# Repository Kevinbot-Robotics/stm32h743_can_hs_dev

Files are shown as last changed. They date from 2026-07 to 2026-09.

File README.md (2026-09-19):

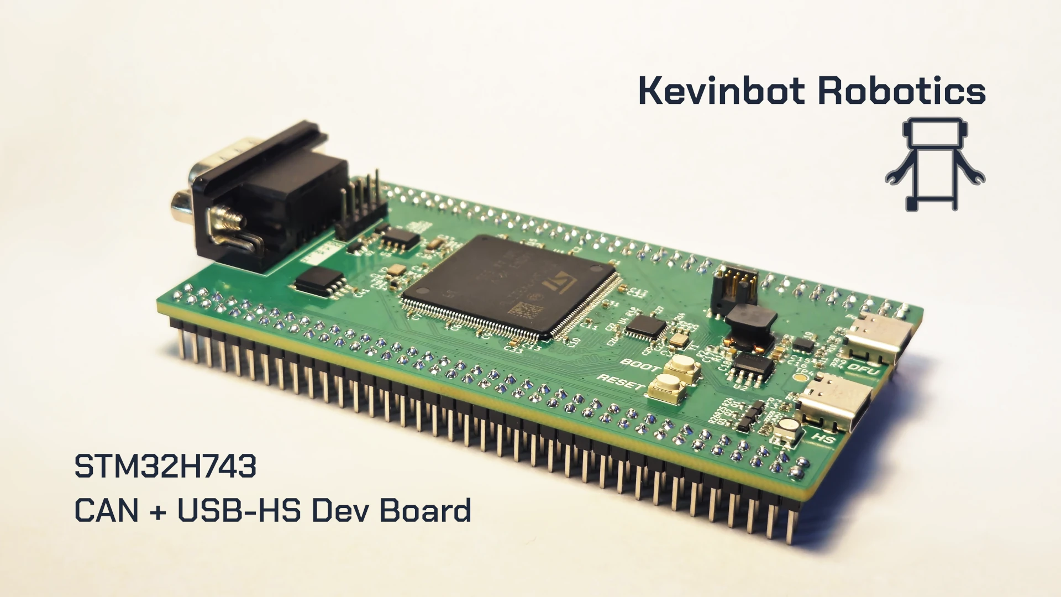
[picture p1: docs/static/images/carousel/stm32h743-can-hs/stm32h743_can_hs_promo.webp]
Board Image


# STM32H743 CAN + USB-HS Dev Board

An STM32H743 development board with on-board USB-HS and CAN-FD (up to 8Mbit/s)

## Documentation

Docs are available on [kevinbot.net](https://kevinbot.net/dev/stm32h743-can-hs/).
Documentation is licensed under the [CC BY-SA 4.0](https://creativecommons.org/licenses/by-sa/4.0/) license.

## Features

* STM32H743
* CAN-FD using DE-9 Industrial connector
* High Speed USB 2.0 using USB3300 ULPI PHY
* 128Mbit QuadSPI NOR flash
* SWD and JTAG debug using STDC14 Debug connector
* USB-C ports for DFU and HS
* Power path switching from HS and DFU port
* RGB LED
* Boot/Reset buttons

---

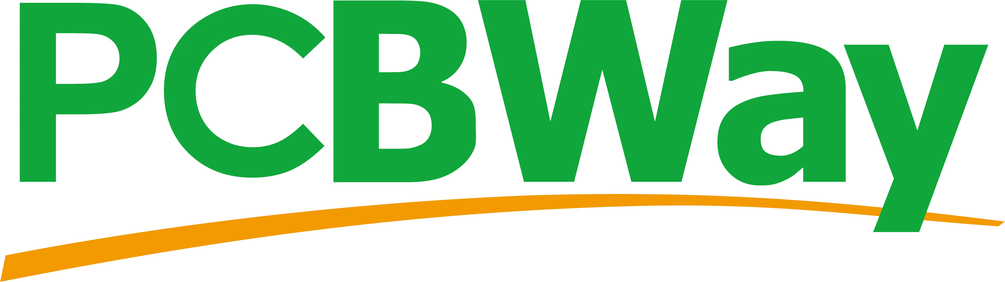
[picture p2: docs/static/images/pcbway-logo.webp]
PCBWay logo


Prototypes for this project were sponsored by [PCBWay](https://www.pcbway.com/).

With their high-quality advanced PCB fabrication, fast turnaround, and excellent customer service, I recommend them for all of your PCB needs.

[Order online here, for as low at $5](https://www.pcbway.com/orderonline.aspx)

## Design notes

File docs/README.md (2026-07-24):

# STM32H743 CAN + USB-HS — Documentation

Source for the STM32H743 CAN + USB-HS dev board documentation.

This is a self-contained [Hugo](https://gohugo.io/) module. It is consumed by
[kevinbot.net](https://kevinbot.net) as a Hugo module, but it can also be built
and previewed on its own so the docs can be published and contributed to
independently of the main site.

## Preview locally

Requires the extended edition of Hugo.

```sh
hugo server
```

The docs are served under `/dev/stm32h743-can-hs/` (the same path they occupy on
kevinbot.net), so every internal link and asset path resolves identically in
both builds.

## Layout

- `content/` — the documentation pages (Markdown).
- `static/` — interactive BOM, Pinion pinout viewer, and carousel images.
- `data/galleries/` — image list for the front-page carousel.
- `layouts/shortcodes/` — the `carousel` and `pinion` shortcodes (mirrored from
  kevinbot.net so this site renders standalone; the main site's copies take
  precedence when integrated).

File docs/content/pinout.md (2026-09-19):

---
title: "Pinout"
editURL: https://github.com/Kevinbot-Robotics/stm32h743_can_hs_dev/edit/master/docs/content/pinout.md
weight: 1
prev: /dev/stm32h743-can-hs
---

An interactive pinout diagram is available below. JavaScript is required to view it. Use the link below if it doesn't load automatically.

{{< pinion spec="/pinion-rev1.1/stm32h743-can-hs" >}}
<a href="/pinion-rev1.1/stm32h743-can-hs/pinion.html" target="_blank">Open Interactive Diagram in New Tab</a>

{{< callout type="note" >}}
  Looking for the Rev 1.0 pinout? [Click here](/pinion-rev1.0/stm32h743-can-hs/pinion.html)
{{< /callout >}}

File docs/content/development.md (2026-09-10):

---
title: "Development"
editURL: https://github.com/Kevinbot-Robotics/stm32h743_can_hs_dev/edit/master/docs/content/development.md
weight: 4
---

This project requires [KiCad](https://www.kicad.org/) 10.0.5 or compatible.

### Building documentation

This project uses a Makefile for building. Documentation requires [Hugo](https://gohugo.io/), and a system Python interpreter with the KiCAD API.

Only Linux is supported for now. WSL within Windows may work.

Run `make all` to create a Python environment, rebuild docs, pinout diagrams, and the interactive BOM.

{{< callout type="warning" >}}
  This step may take a few minutes, use `make docs` if you only want to update the docs without rebuilding the interactive assets.
{{< /callout >}}

Run `make docs` to rebuild the markdown documentation, re-using the pre-built interactive assets (they are included in this repo)

Run `make ibom` to rebuild the interactive BOM. The new BOM will be located in the `bom/` directory, and `docs/static/ibom/`

Run `make pinout` to rebuild the interactive pinout. The built pinout will be located in `docs/static/pinion/`

{{< callout type="warning" >}}
  This step may take a few minutes.
{{< /callout >}}

Run `make clean` to remove the Python environment and built docs.

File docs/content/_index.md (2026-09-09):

---
title: STM32H743 CAN + USB-HS Dev Board
editURL: https://github.com/Kevinbot-Robotics/stm32h743_can_hs_dev/edit/master/docs/content/_index.md
cascade:
  type: docs
aliases:
  - /743-can-hs
  - /h743-can-hs
next: pinout
---

An STM32H743 development board with on-board USB-HS and CAN-FD (up to 8Mbit/s)

{{< carousel gallery="stm32h743-can-hs" >}}

{{< hextra/hero-button text="View Project on GitHub" link="https://github.com/Kevinbot-Robotics/stm32h743_can_hs_dev" >}}

---

<div style="display: flex; flex-direction: row; align-items: center; gap: 1em;">
    <a href="https://certification.oshwa.org/us002841.html">
    OSHW US2841
    OSHW US2841
    </a>
    <p>This project is <a href="https://certification.oshwa.org/us002841.html">certified</a> by the Open Source Hardware Association</p>
</div>

<style>

.light-only {
  display: block;
}

.dark-only {
  display: none;
}

.dark .light-only,
html.dark .light-only {
  display: none;
}

.dark .dark-only,
html.dark .dark-only {
  display: block;
}
</style>

---

## Features

* STM32H743 microcontroller with 116 I/O pins exposed
* CAN-FD using DE-9 connector using industrial standard pinout
* High Speed USB 2.0 using USB3300 ULPI PHY
* 128Mbit QuadSPI NOR flash
* SWD debug using MIPI-10 Cortex Debug connector
* USB-C ports for DFU and HS
* Power path switching from HS and DFU port and backfeed prevention
* RGB LED
* Boot/Reset buttons

## Programming

The board can be programmed via the DFU port using the DFU bootloader by pressing BOOT and RESET to put the board into DFU mode.

The board may also be programmed/debugged using the MIPI-10 Cortex Debug connector.

## Development

The board supports any toolchain that supports the STM32H743 microcontroller, including the STM32CubeIDE and Zephyr.
Zephyr device trees and board configurations will be available in the future.

## Design Resources

{{< cards cols="3" >}}
  {{< card
    title="Simplified CAD Model"
    subtitle="Simplified 3D CAD model with passive components removed, STEP format"
    image="/images/resources/simplified-cad.png"
    link="https://raw.githubusercontent.com/Kevinbot-Robotics/stm32h743_can_hs_dev/refs/heads/master/stm32h743_can_hs_simplified.step"
  >}}
  {{< card
    title="Full CAD Model"
    subtitle="Complete 3D CAD model including passive components, STEP format"
    image="/images/resources/complete-cad.png"
    link="https://raw.githubusercontent.com/Kevinbot-Robotics/stm32h743_can_hs_dev/refs/heads/master/stm32h743_can_hs_full.step"
  >}}
  {{< card
    title="KiCAD Symbol & Footprint"
    subtitle="Coming Soon!<br>KiCAD 10 Symbol, Footprint, and 3D Model"
    image="/images/resources/coming-soon.png"
  >}}
{{< /cards >}}

---

PCBWay logo

Prototypes for this project were sponsored by [PCBWay](https://www.pcbway.com/).

With their high-quality advanced PCB fabrication, fast turnaround, and excellent customer service, I recommend them for all of your PCB needs.

[Order online here, for as low at $5](https://www.pcbway.com/orderonline.aspx)

## License

Hardware is licensed under the [GPL-3.0](https://www.gnu.org/licenses/gpl-3.0.html) license.
<br>
Documentation is licensed under the [CC BY-SA 4.0](https://creativecommons.org/licenses/by-sa/4.0/) license.

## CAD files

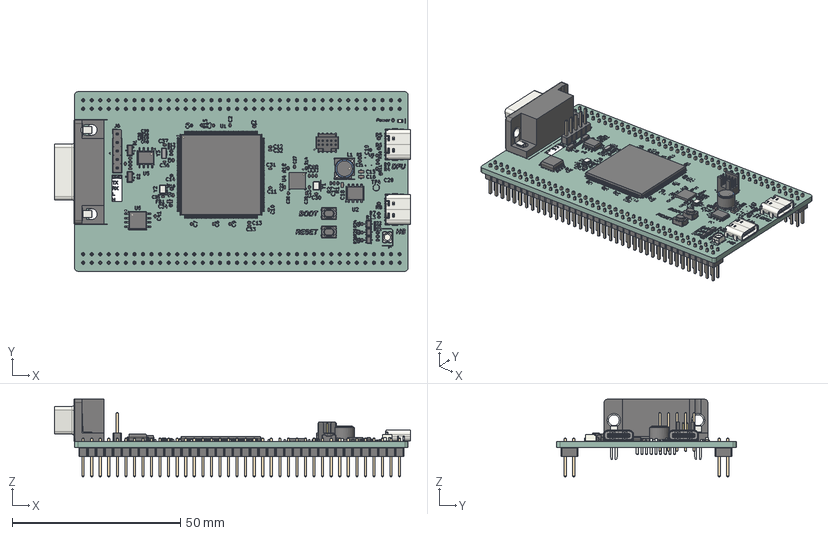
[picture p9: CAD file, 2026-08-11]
stm32h743_can_hs_full.step
105.7 x 53.3 x 23.0 mm
R_0402_1005Metric x 27
C_0402_1005Metric x 38
C_0603_1608Metric x 3
DSUB-9_Pins_Horizontal_P2.77x2.84mm_EdgePinOffset4.94mm_Housed_ MountingHolesOffset4.94mm
SW_SPST_PTS810 x 2
L_0603_1608Metric
USB_C_Receptacle_16P_TopMnt_Horizontal_GCT_USB4105-xx-A x 2
LED_RGB_Wuerth-PLCC4_3.2x2.8mm_150141M173100
LQFP-176_24x24mm_P0.5mm
Oscillator_SMD_SeikoEpson_SG210-4Pin_2.5x2.0mm x 2
TI_SO-PowerPAD-8
SOIC-8_5.3x5.3mm_P1.27mm
SOT-23 x 2
SOT-323_SC-70 x 3
SOIC-8_3.9x4.9mm_P1.27mm
L_TDK_SLF6045
PinHeader_1x05_P254mm_Vertical
FTSH-105-01-L-DV-K_body
FTSH-105-01-L-DV-K_pins1
FTSH-105-01-L-DV-K_pins2
LED_0603_1608Metric
Crystal_SMD_3215-2Pin_3.2x1.5mm
QFN-32-1EP_5x5mm_Pitch0.5mm
PinHeader_2x38_P254mm_Vertical x 2
stm32h743_can_hs_silkscreen x 2
stm32h743_can_hs_PCB

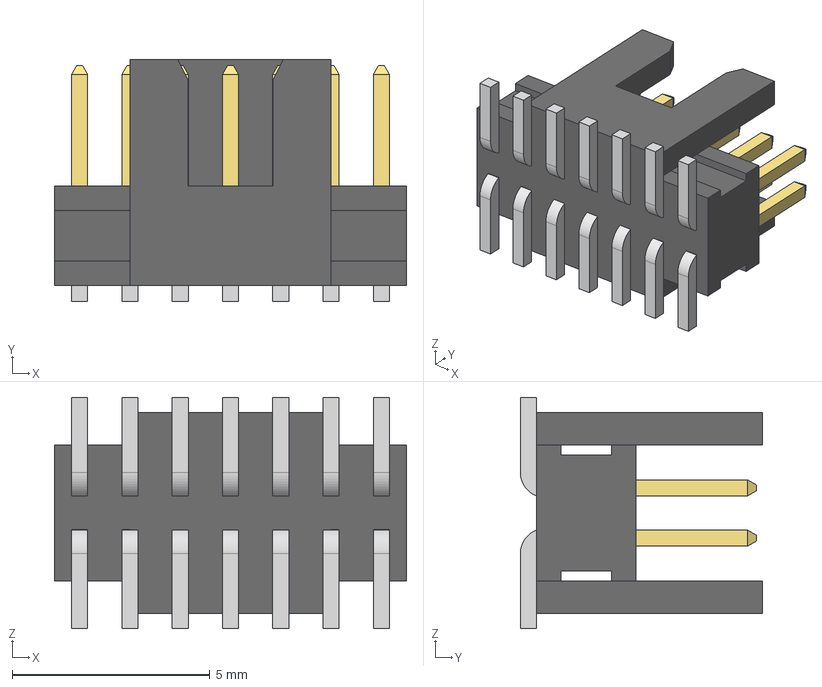
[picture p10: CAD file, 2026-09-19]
SAMTEC_FTSH-107-01-X-DV-K.3dmodels/FTSH-107-01-L-DV-K.stp
8.89 x 6.12 x 5.84 mm
FTSH-107-01-L-DV-K_body
FTSH-107-01-L-DV-K_pins1
FTSH-107-01-L-DV-K_pins2

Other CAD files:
stm32h743_can_hs_simplified.step

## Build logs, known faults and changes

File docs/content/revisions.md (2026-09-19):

---
title: "Revision History"
editURL: https://github.com/Kevinbot-Robotics/stm32h743_can_hs_dev/edit/master/docs/content/revisions.md
weight: 3
---

## 1.1

* Replace debug header with STDC14 to include JTAG support and UART
* Added PA13 to exposed I/O pins
* Added silkscreen label for debug header

## 1.0

* Initial release

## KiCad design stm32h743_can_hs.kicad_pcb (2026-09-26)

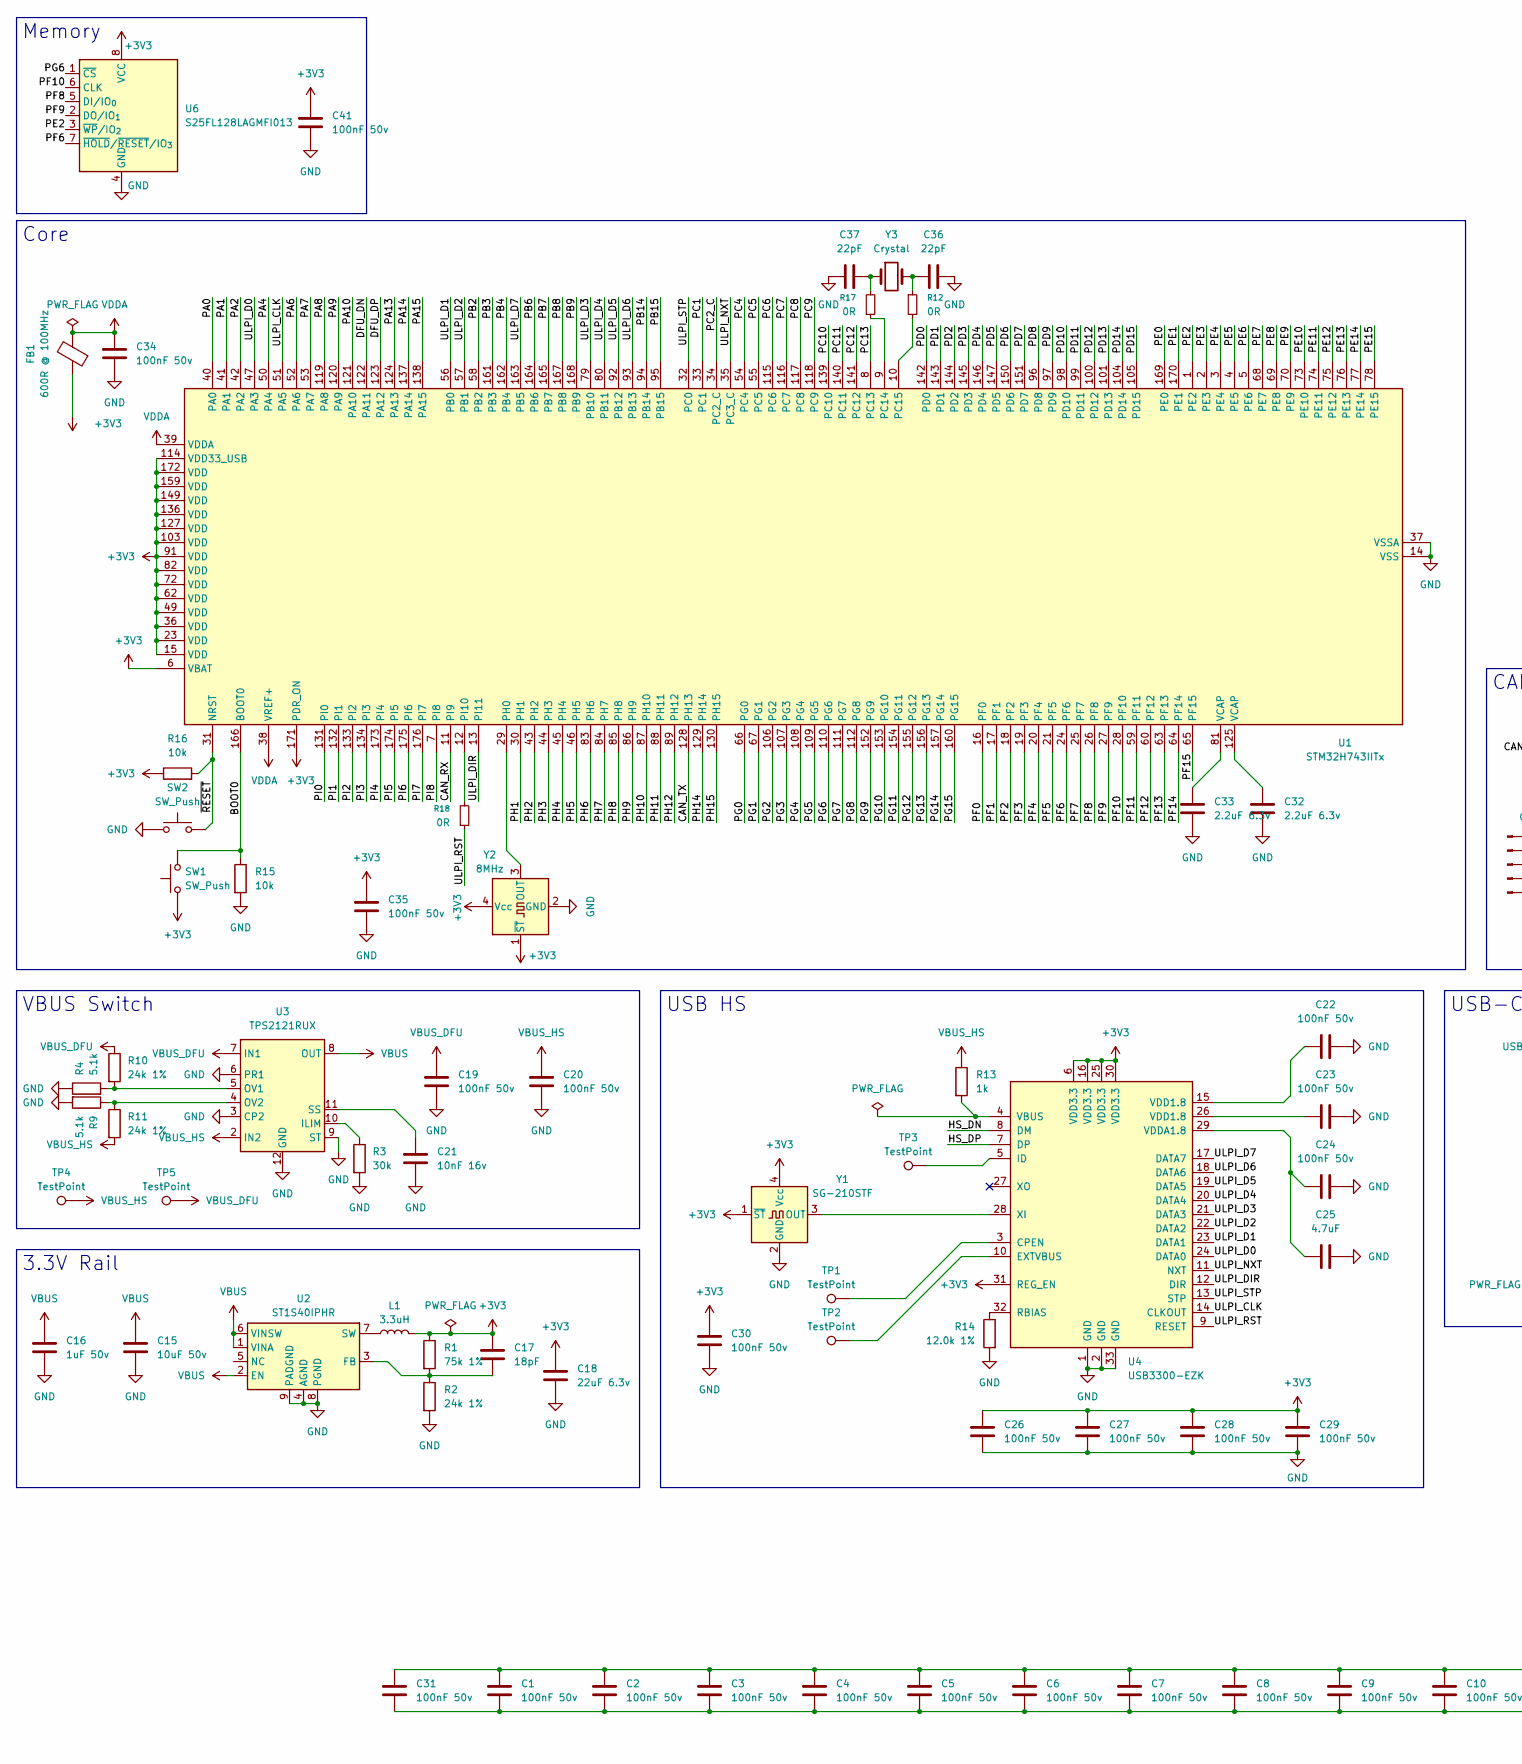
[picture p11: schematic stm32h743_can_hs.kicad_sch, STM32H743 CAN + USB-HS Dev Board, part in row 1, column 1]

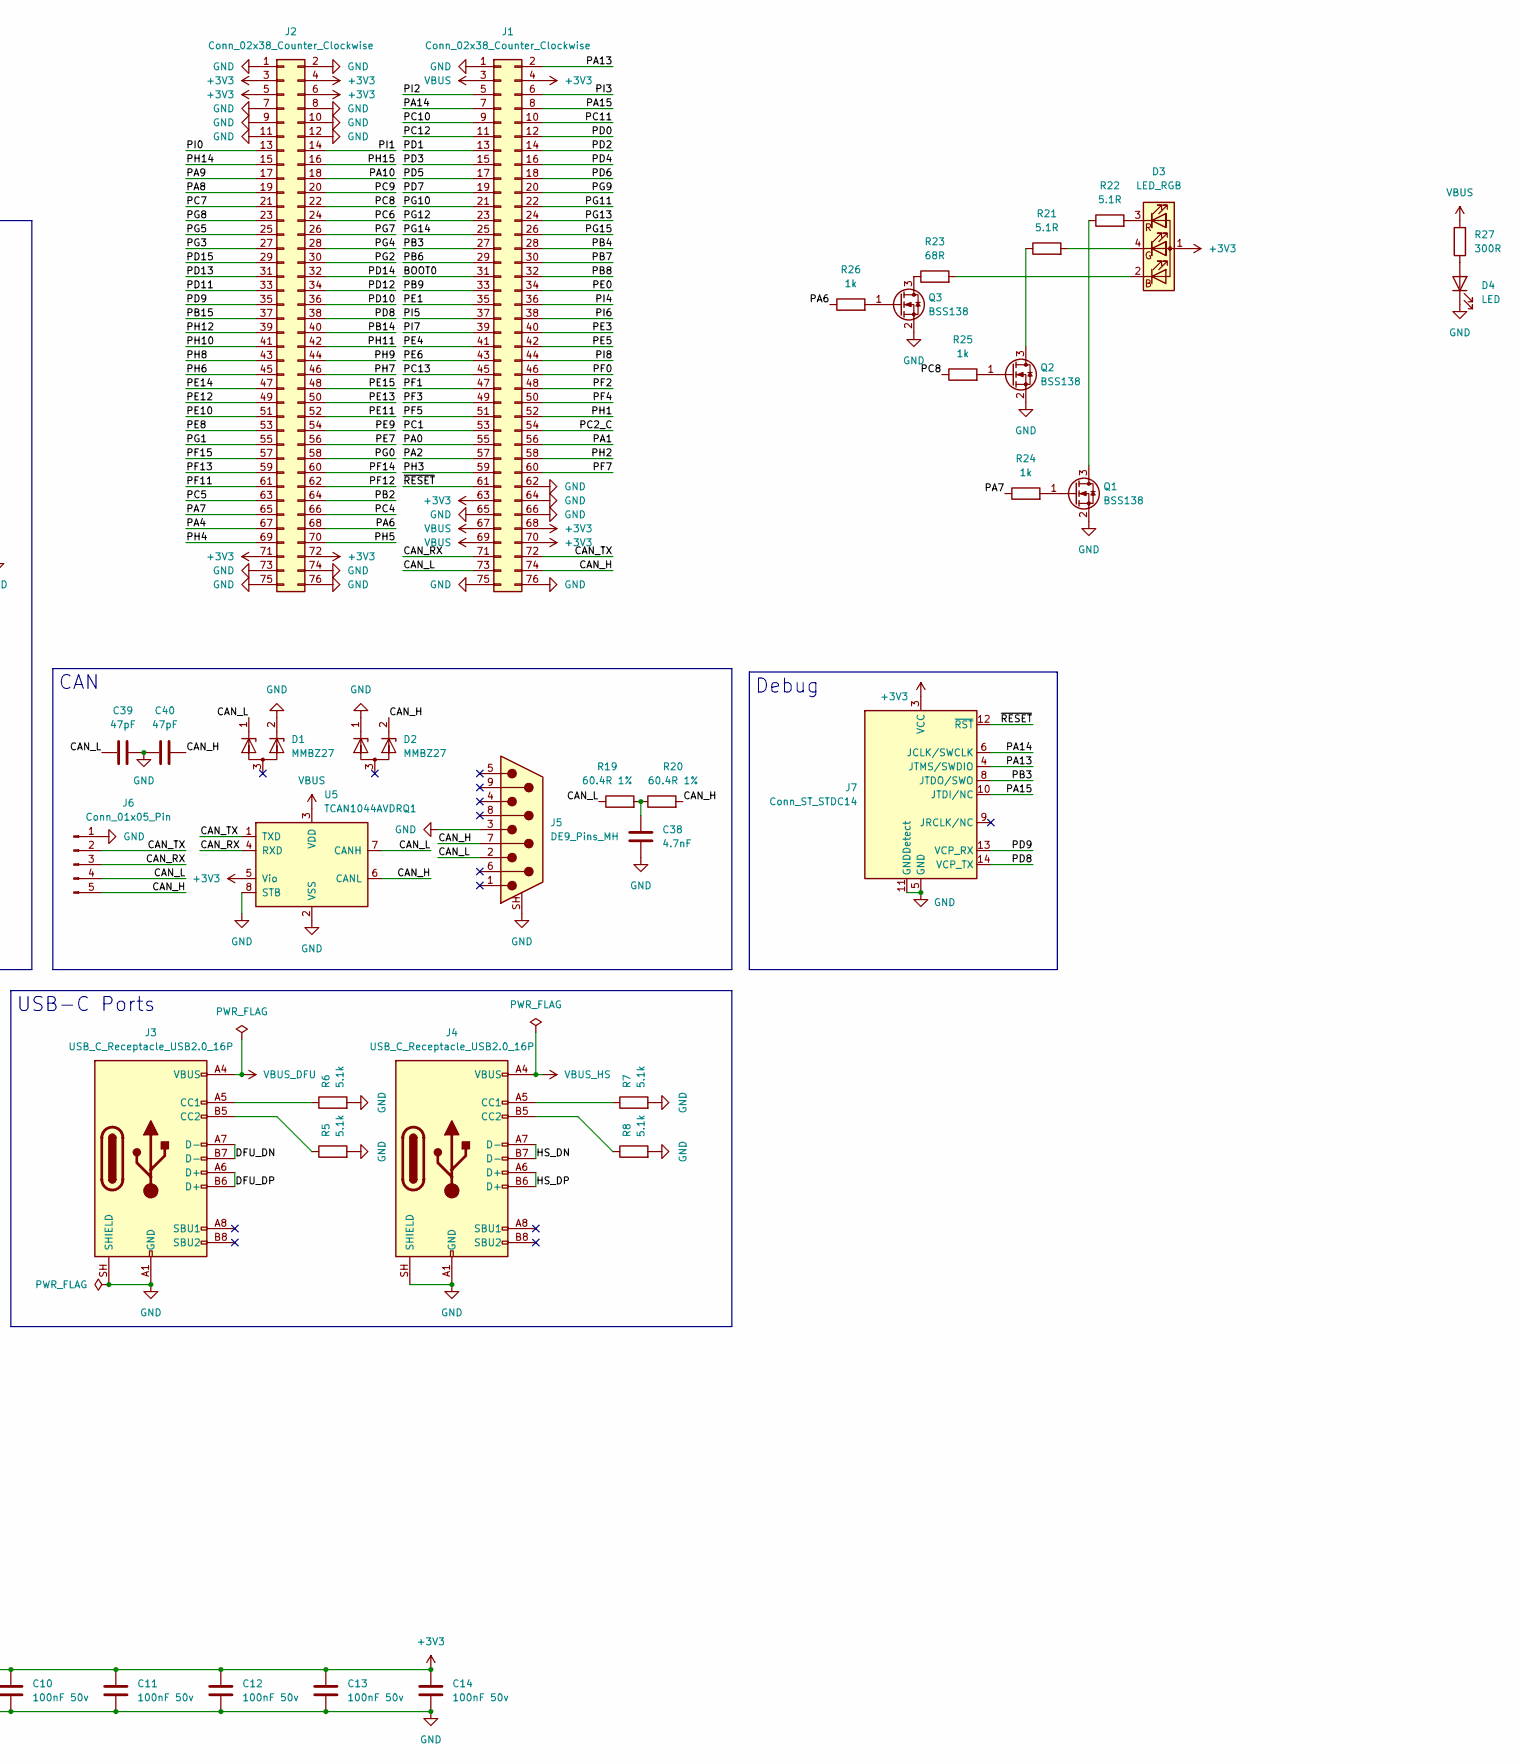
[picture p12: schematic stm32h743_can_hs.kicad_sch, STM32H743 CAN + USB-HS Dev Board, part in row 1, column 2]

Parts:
C1, C2, C3, C4, C5, C6, C7, C8, C9, C10, C11, C12, C13, C14, C19, C20, C22, C23, C24, C26, C27, C28, C29, C30, C31, C34, C35, C41: 100nF 50v; C_0402_1005Metric
C15: 10uF 50v; C_0603_1608Metric
C16: 1uF 50v; C_0603_1608Metric
C17: 18pF; C_0402_1005Metric
C18: 22uF 6.3v; C_0603_1608Metric
C21: 10nF 16v; C_0402_1005Metric
C25: 4.7uF; C_0402_1005Metric
C32, C33: 2.2uF 6.3v; C_0402_1005Metric
C36, C37: 22pF; C_0402_1005Metric
C38: 4.7nF; C_0402_1005Metric
C39, C40: 47pF; C_0402_1005Metric
D1, D2: MMBZ27; SOT-23
D3: LED_RGB; LED_RGB_Wuerth-PLCC4_3.2x2.8mm_150141M173100
D4: LED; LED_0603_1608Metric
FB1: 600R @ 100MHz; L_0603_1608Metric
J1, J2: Conn_02x38_Counter_Clockwise; PinHeader_2x38_P2.54mm_Vertical
J3, J4: USB_C_Receptacle_USB2.0_16P; USB_C_Receptacle_GCT_USB4105-xx-A_16P_TopMnt_Horizontal
J5: DE9_Pins_MH; DSUB-9_Pins_Horizontal_P2.77x2.84mm_EdgePinOffset4.94mm_Hou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
J6: Conn_01x05_Pin; PinHeader_1x05_P2.54mm_Vertical
J7: Conn_ST_STDC14; SAMTEC_FTSH-107-01-X-DV-K
L1: 3.3uH; L_TDK_VLS6045EX_VLS6045AF
Q1, Q2, Q3: BSS138; SOT-323_SC-70
R1: 75k 1%; R_0402_1005Metric
R2, R10, R11: 24k 1%; R_0402_1005Metric
R3: 30k; R_0402_1005Metric
R4, R5, R6, R7, R8, R9: 5.1k; R_0402_1005Metric
R12, R17, R18: 0R; R_0402_1005Metric
R13, R24, R25, R26: 1k; R_0402_1005Metric
R14: 12.0k 1%; R_0402_1005Metric
R15, R16: 10k; R_0402_1005Metric
R19, R20: 60.4R 1%; R_0402_1005Metric
R21, R22: 5.1R; R_0402_1005Metric
R23: 68R; R_0402_1005Metric
R27: 300R; R_0402_1005Metric
SW1, SW2: SW_Push; SW_SPST_PTS810
TP1, TP2, TP3, TP4, TP5: TestPoint; TestPoint_Pad_D1.5mm
U1: STM32H743IITx; LQFP-176_24x24mm_P0.5mm
U2: ST1S40IPHR; TI_SO-PowerPAD-8
U3: TPS2121RUX; Texas_VQFN-HR-12_2x2.5mm_P0.5mm
U4: USB3300-EZK; QFN-32-1EP_5x5mm_P0.5mm_EP3.45x3.45mm
U5: TCAN1044AVDRQ1; SOIC-8_3.9x4.9mm_P1.27mm
U6: S25FL128LAGMFI013; SOIC-8_5.3x5.3mm_P1.27mm
Y1: SG-210STF; Oscillator_SMD_SeikoEpson_SG210-4Pin_2.5x2.0mm
Y2: 8MHz; Oscillator_SMD_SeikoEpson_SG210-4Pin_2.5x2.0mm
Y3: Crystal; Crystal_SMD_3215-2Pin_3.2x1.5mm

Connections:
+3V3: C1.1, C2.1, C3.1, C4.1, C5.1, C6.1, C7.1, C8.1, C9.1, C10.1, C11.1, C12.1, C13.1, C14.1, C17.1, C18.1, C26.1, C27.1, C28.1, C29.1, C30.1, C31.1, C35.1, C41.1, D3.1 (A), FB1.1, J1.4, J1.63, J1.68, J1.70, J2.3, J2.4, J2.5, J2.6, J2.71, J2.72, J7.3 (VCC), L1.2, R1.1, R16.1, SW1.1, U1.6 (VBAT), U1.15 (VDD), U1.23 (VDD), U1.36 (VDD), U1.49 (VDD), U1.62 (VDD), U1.72 (VDD), U1.82 (VDD), U1.91 (VDD), U1.103 (VDD), U1.114 (VDD33_USB), U1.127 (VDD), U1.136 (VDD), U1.149 (VDD), U1.159 (VDD), U1.171 (PDR_ON), U1.172 (VDD), U4.6 (VDD3.3), U4.16 (VDD3.3), U4.25 (VDD3.3), U4.30 (VDD3.3), U4.31 (REG_EN), U5.5 (Vio), U6.8 (VCC), Y1.1 (~ST), Y1.4 (Vcc), Y2.1 (~ST), Y2.4 (Vcc)
/BOOT0: J1.31, R15.1, SW1.2, U1.166 (BOOT0)
/CAN_H: C40.2, D2.2 (K), J1.74, J5.7, J6.5, R20.2, U5.6 (CANL)
/CAN_L: C39.1, D1.1 (K), J1.73, J5.2, J6.4, R19.1, U5.7 (CANH)
/CAN_RX: J1.71, J6.3, U1.11 (PI9), U5.4 (RXD)
/CAN_TX: J1.72, J6.2, U1.128 (PH13), U5.1 (TXD)
/DFU_DN: J3.A7 (D-), J3.B7 (D-), U1.122 (PA11)
/DFU_DP: J3.A6 (D+), J3.B6 (D+), U1.123 (PA12)
/HS_DN: J4.A7 (D-), J4.B7 (D-), U4.8 (DM)
/HS_DP: J4.A6 (D+), J4.B6 (D+), U4.7 (DP)
/PA0: J1.55, U1.40 (PA0)
/PA1: J1.56, U1.41 (PA1)
/PA2: J1.57, U1.42 (PA2)
/PA4: J2.67, U1.50 (PA4)
/PA6: J2.68, R26.1, U1.52 (PA6)
/PA7: J2.65, R24.1, U1.53 (PA7)
/PA8: J2.19, U1.119 (PA8)
/PA9: J2.17, U1.120 (PA9)
/PA10: J2.18, U1.121 (PA10)
/PA13: J1.2, J7.4 (JTMS/SWDIO), U1.124 (PA13)
/PA14: J1.7, J7.6 (JCLK/SWCLK), U1.137 (PA14)
/PA15: J1.8, J7.10 (JTDI/NC), U1.138 (PA15)
/PB2: J2.64, U1.58 (PB2)
/PB3: J1.27, J7.8 (JTDO/SWO), U1.161 (PB3)
/PB4: J1.28, U1.162 (PB4)
/PB6: J1.29, U1.164 (PB6)
/PB7: J1.30, U1.165 (PB7)
/PB8: J1.32, U1.167 (PB8)
/PB9: J1.33, U1.168 (PB9)
/PB14: J2.40, U1.94 (PB14)
/PB15: J2.37, U1.95 (PB15)
/PC1: J1.53, U1.33 (PC1)
/PC2_C: J1.54, U1.34 (PC2_C)
/PC4: J2.66, U1.54 (PC4)
/PC5: J2.63, U1.55 (PC5)
/PC6: J2.24, U1.115 (PC6)
/PC7: J2.21, U1.116 (PC7)
/PC8: J2.22, R25.1, U1.117 (PC8)
/PC9: J2.20, U1.118 (PC9)
/PC10: J1.9, U1.139 (PC10)
/PC11: J1.10, U1.140 (PC11)
/PC12: J1.11, U1.141 (PC12)
/PC13: J1.45, U1.8 (PC13)
/PD0: J1.12, U1.142 (PD0)
/PD1: J1.13, U1.143 (PD1)
/PD2: J1.14, U1.144 (PD2)
/PD3: J1.15, U1.145 (PD3)
/PD4: J1.16, U1.146 (PD4)
/PD5: J1.17, U1.147 (PD5)
/PD6: J1.18, U1.150 (PD6)
/PD7: J1.19, U1.151 (PD7)
/PD8: J2.38, J7.14 (VCP_TX), U1.96 (PD8)
/PD9: J2.35, J7.13 (VCP_RX), U1.97 (PD9)
/PD10: J2.36, U1.98 (PD10)
/PD11: J2.33, U1.99 (PD11)
/PD12: J2.34, U1.100 (PD12)
/PD13: J2.31, U1.101 (PD13)
/PD14: J2.32, U1.104 (PD14)
/PD15: J2.29, U1.105 (PD15)
/PE0: J1.34, U1.169 (PE0)
/PE1: J1.35, U1.170 (PE1)
/PE2: U1.1 (PE2), U6.3 (~WP/IO_{2})
/PE3: J1.40, U1.2 (PE3)
/PE4: J1.41, U1.3 (PE4)
/PE5: J1.42, U1.4 (PE5)
/PE6: J1.43, U1.5 (PE6)
/PE7: J2.56, U1.68 (PE7)
/PE8: J2.53, U1.69 (PE8)
/PE9: J2.54, U1.70 (PE9)
/PE10: J2.51, U1.73 (PE10)
/PE11: J2.52, U1.74 (PE11)
/PE12: J2.49, U1.75 (PE12)
/PE13: J2.50, U1.76 (PE13)
/PE14: J2.47, U1.77 (PE14)
/PE15: J2.48, U1.78 (PE15)
/PF0: J1.46, U1.16 (PF0)
/PF1: J1.47, U1.17 (PF1)
/PF2: J1.48, U1.18 (PF2)
/PF3: J1.49, U1.19 (PF3)
/PF4: J1.50, U1.20 (PF4)
/PF5: J1.51, U1.21 (PF5)
/PF6: U1.24 (PF6), U6.7 (~HOLD/~RESET/IO_{3})
/PF7: J1.60, U1.25 (PF7)
/PF8: U1.26 (PF8), U6.5 (DI/IO_{0})
/PF9: U1.27 (PF9), U6.2 (DO/IO_{1})
/PF10: U1.28 (PF10), U6.6 (CLK)
/PF11: J2.61, U1.59 (PF11)
/PF12: J2.62, U1.60 (PF12)
/PF13: J2.59, U1.63 (PF13)
/PF14: J2.60, U1.64 (PF14)
/PF15: J2.57, U1.65 (PF15)
/PG0: J2.58, U1.66 (PG0)
/PG1: J2.55, U1.67 (PG1)
/PG2: J2.30, U1.106 (PG2)
/PG3: J2.27, U1.107 (PG3)
/PG4: J2.28, U1.108 (PG4)
/PG5: J2.25, U1.109 (PG5)
/PG6: U1.110 (PG6), U6.1 (~CS)
/PG7: J2.26, U1.111 (PG7)
/PG8: J2.23, U1.112 (PG8)
/PG9: J1.20, U1.152 (PG9)
/PG10: J1.21, U1.153 (PG10)
/PG11: J1.22, U1.154 (PG11)
/PG12: J1.23, U1.155 (PG12)
/PG13: J1.24, U1.156 (PG13)
/PG14: J1.25, U1.157 (PG14)
/PG15: J1.26, U1.160 (PG15)
/PH1: J1.52, U1.30 (PH1)
/PH2: J1.58, U1.43 (PH2)
/PH3: J1.59, U1.44 (PH3)
/PH4: J2.69, U1.45 (PH4)
/PH5: J2.70, U1.46 (PH5)
/PH6: J2.45, U1.83 (PH6)
/PH7: J2.46, U1.84 (PH7)
/PH8: J2.43, U1.85 (PH8)
/PH9: J2.44, U1.86 (PH9)
/PH10: J2.41, U1.87 (PH10)
/PH11: J2.42, U1.88 (PH11)
/PH12: J2.39, U1.89 (PH12)
/PH14: J2.15, U1.129 (PH14)
/PH15: J2.16, U1.130 (PH15)
/PI0: J2.13, U1.131 (PI0)
/PI1: J2.14, U1.132 (PI1)
/PI2: J1.5, U1.133 (PI2)
/PI3: J1.6, U1.134 (PI3)
/PI4: J1.36, U1.173 (PI4)
/PI5: J1.37, U1.174 (PI5)
/PI6: J1.38, U1.175 (PI6)
/PI7: J1.39, U1.176 (PI7)
/PI8: J1.44, U1.7 (PI8)
/ULPI_CLK: U1.51 (PA5), U4.14 (CLKOUT)
/ULPI_D0: U1.47 (PA3), U4.24 (DATA0)
/ULPI_D1: U1.56 (PB0), U4.23 (DATA1)
/ULPI_D2: U1.57 (PB1), U4.22 (DATA2)
/ULPI_D3: U1.79 (PB10), U4.21 (DATA3)
/ULPI_D4: U1.80 (PB11), U4.20 (DATA4)
/ULPI_D5: U1.92 (PB12), U4.19 (DATA5)
/ULPI_D6: U1.93 (PB13), U4.18 (DATA6)
/ULPI_D7: U1.163 (PB5), U4.17 (DATA7)
/ULPI_DIR: U1.13 (PI11), U4.12 (DIR)
/ULPI_NXT: U1.35 (PC3_C), U4.11 (NXT)
/ULPI_RST: R18.1, U4.9 (RESET)
/ULPI_STP: U1.32 (PC0), U4.13 (STP)
/~RESET: J1.61, J7.12 (~RST), R16.2, SW2.2, U1.31 (NRST)
GND: C1.2, C2.2, C3.2, C4.2, C5.2, C6.2, C7.2, C8.2, C9.2, C10.2, C11.2, C12.2, C13.2, C14.2, C15.2, C16.2, C18.2, C19.2, C20.2, C21.2, C22.2, C23.2, C24.2, C25.2, C26.2, C27.2, C28.2, C29.2, C30.2, C31.2, C32.2, C33.2, C34.2, C35.2, C36.2, C37.1, C38.2, C39.2, C40.1, C41.2, D1.2 (K), D2.1 (K), D4.1 (K), J1.1, J1.62, J1.64, J1.65, J1.66, J1.75, J1.76, J2.1, J2.2, J2.7, J2.8, J2.9, J2.10, J2.11, J2.12, J2.73, J2.74, J2.75, J2.76, J3.A1 (GND), J3.A12 (GND), J3.B1 (GND), J3.B12 (GND), J3.SH (SHIELD), J4.A1 (GND), J4.A12 (GND), J4.B1 (GND), J4.B12 (GND), J4.SH (SHIELD), J5.3, J5.SH (PAD), J6.1, J7.5 (GND), J7.7 (GND), J7.11 (GNDDetect), Q1.2 (S), Q2.2 (S), Q3.2 (S), R2.2, R3.2, R4.1, R5.2, R6.2, R7.2, R8.2, R9.2, R14.2, R15.2, SW2.1, U1.14 (VSS), U1.22 (VSS), U1.37 (VSSA), U1.48 (VSS), U1.61 (VSS), U1.71 (VSS), U1.90 (VSS), U1.102 (VSS), U1.113 (VSS), U1.126 (VSS), U1.135 (VSS), U1.148 (VSS), U1.158 (VSS), U2.4 (AGND), U2.8 (PGND), U2.9 (PADGND), U3.3 (CP2), U3.6 (PR1), U3.9 (ST), U3.12 (GND), U4.1 (GND), U4.2 (GND), U4.33 (GND), U5.2 (VSS), U5.8 (STB), U6.4 (GND), Y1.2 (GND), Y2.2 (GND)
unnamed: C22.1, U4.15 (VDD1.8)
unnamed: C23.1, U4.26 (VDD1.8)
unnamed: C32.1, U1.125 (VCAP)
unnamed: C33.1, U1.81 (VCAP)
unnamed: C36.1, R12.1, Y3.2
unnamed: C37.2, R17.2, Y3.1
unnamed: C38.1, R19.2, R20.1
unnamed: D3.2 (BK), R23.2
unnamed: D3.4 (GK), R21.2
unnamed: D3.3 (RK), R22.2
unnamed: D4.2 (A), R27.1
unnamed: J3.A5 (CC1), R6.1
unnamed: J3.B5 (CC2), R5.1
unnamed: J4.A5 (CC1), R7.1
unnamed: J4.B5 (CC2), R8.1
unnamed: Q1.3 (D), R22.1
unnamed: Q1.1 (G), R24.2
unnamed: Q2.3 (D), R21.1
unnamed: Q2.1 (G), R25.2
unnamed: Q3.3 (D), R23.1
unnamed: Q3.1 (G), R26.2
unnamed: R17.1, U1.9 (PC14)
unnamed: R12.2, U1.10 (PC15)
unnamed: U1.29 (PH0), Y2.3 (OUT)
unnamed: R18.2, U1.12 (PI10)
unnamed: C17.2, R1.2, R2.1, U2.3 (FB)
unnamed: L1.1, U2.7 (SW)
unnamed: R3.1, U3.10 (ILIM)
unnamed: R4.2, R10.2, U3.5 (OV1)
unnamed: R9.1, R11.1, U3.4 (OV2)
unnamed: C21.1, U3.11 (SS)
unnamed: TP1.1 (1_1), U4.3 (CPEN)
unnamed: TP2.1 (1_1), U4.10 (EXTVBUS)
unnamed: TP3.1 (1_1), U4.5 (ID)
unnamed: R14.1, U4.32 (RBIAS)
unnamed: R13.2, U4.4 (VBUS)
unnamed: C24.1, C25.1, U4.29 (VDDA1.8)
unnamed: U4.28 (XI), Y1.3 (OUT)
VBUS: C15.1, C16.1, J1.3, J1.67, J1.69, R27.2, U2.1 (VINA), U2.2 (EN), U2.6 (VINSW), U3.1 (OUT), U3.8 (OUT), U5.3 (VDD)
VBUS_DFU: C19.1, J3.A4 (VBUS), J3.A9 (VBUS), J3.B4 (VBUS), J3.B9 (VBUS), R10.1, TP5.1 (1_1), U3.7 (IN1)
VBUS_HS: C20.1, J4.A4 (VBUS), J4.A9 (VBUS), J4.B4 (VBUS), J4.B9 (VBUS), R11.2, R13.1, TP4.1 (1_1), U3.2 (IN2)
VDDA: C34.1, FB1.2, U1.38 (VREF+), U1.39 (VDDA)

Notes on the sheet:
VBUS Switch
USB HS
Debug
Core
USB-C Ports
3.3V Rail
Memory
CAN

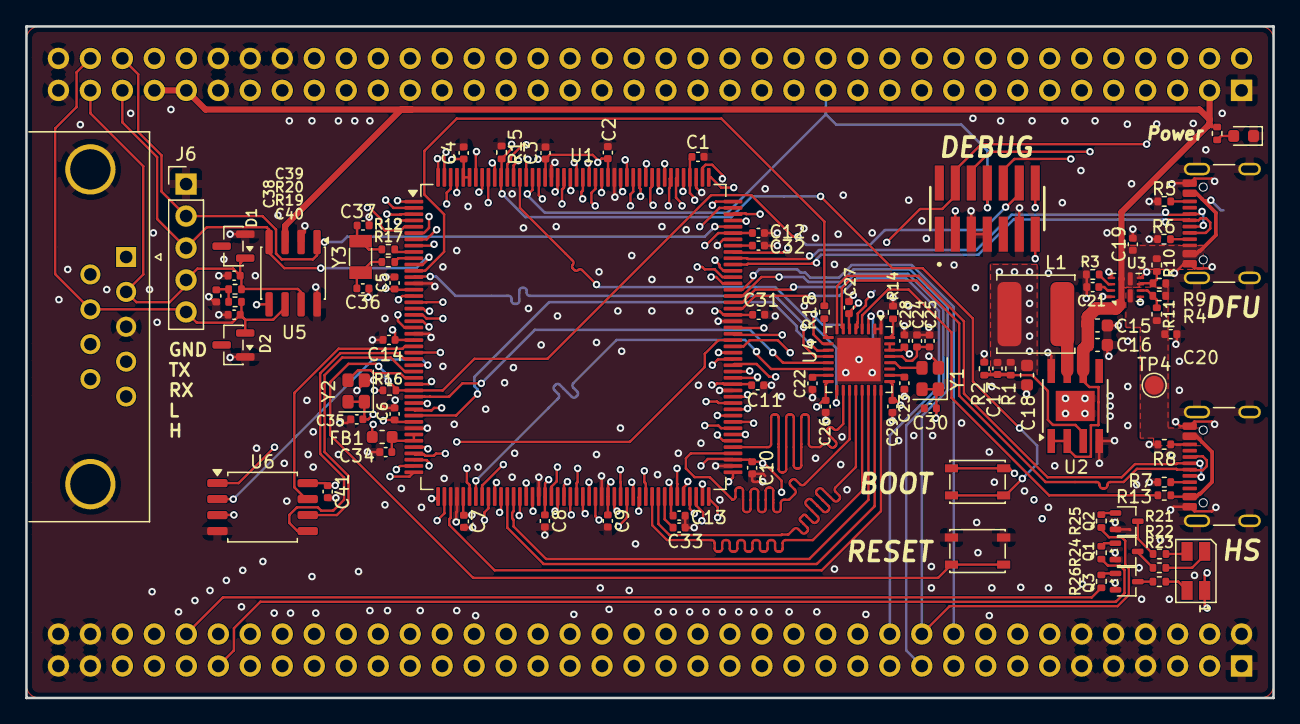
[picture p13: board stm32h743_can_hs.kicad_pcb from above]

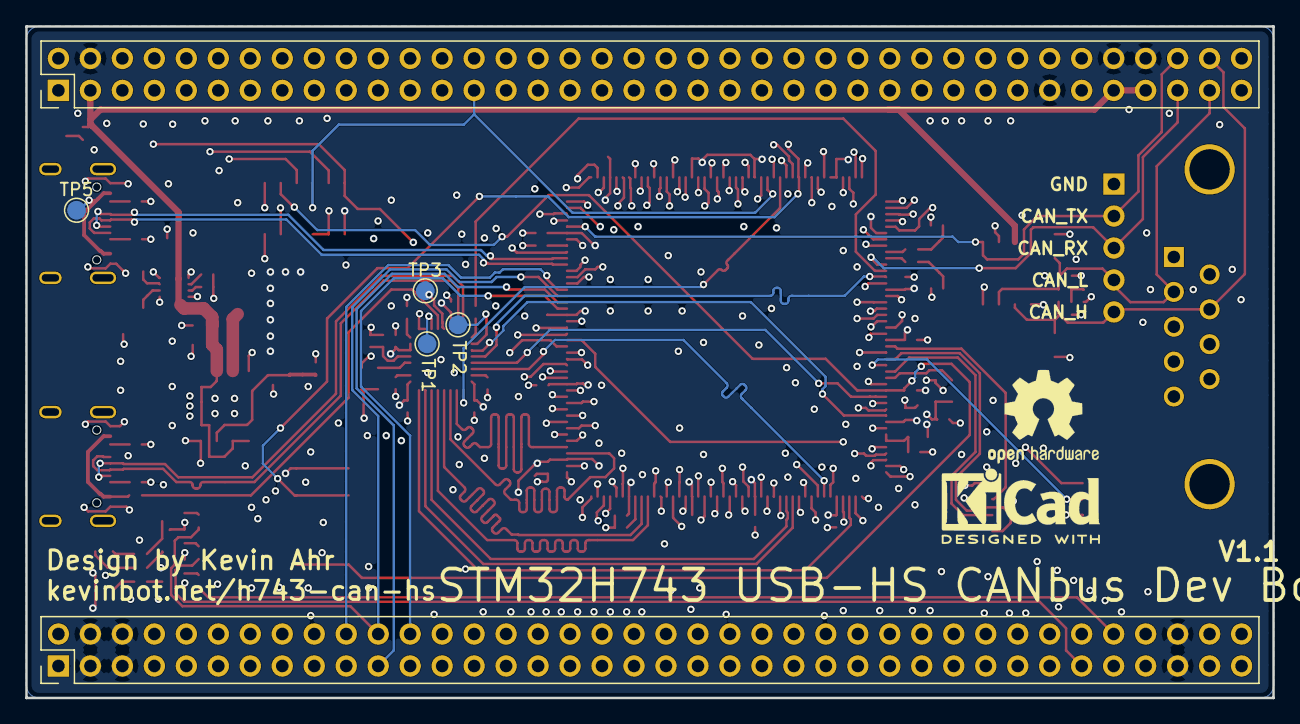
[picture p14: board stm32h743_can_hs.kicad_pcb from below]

Board: 4 copper layers, 99.1 x 53.3 mm, 102 parts (8 on the bottom side), 187 nets.

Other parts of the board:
GFX1: KiCad-Logo2_5mm_SilkScreen
GFX2: OSHW-Logo2_9.8x8mm_SilkScreen

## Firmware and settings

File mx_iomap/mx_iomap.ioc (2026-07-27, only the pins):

Mcu.UserName=STM32H743IITx
PA11.Signal=USB_OTG_FS_DM
PA12.Signal=USB_OTG_FS_DP
PA3.Signal=USB_OTG_HS_ULPI_D0
PA5.Signal=USB_OTG_HS_ULPI_CK
PA6.GPIO_Label=RGB RED
PA6.Signal=S_TIM3_CH1
PA7.GPIO_Label=RGB GREEN
PA7.Signal=S_TIM3_CH2
PB0.Signal=USB_OTG_HS_ULPI_D1
PB1.Signal=USB_OTG_HS_ULPI_D2
PB10.Signal=USB_OTG_HS_ULPI_D3
PB11.Signal=USB_OTG_HS_ULPI_D4
PB12.Signal=USB_OTG_HS_ULPI_D5
PB13.Signal=USB_OTG_HS_ULPI_D6
PB5.Signal=USB_OTG_HS_ULPI_D7
PC0.Signal=USB_OTG_HS_ULPI_STP
PC3_C.Signal=USB_OTG_HS_ULPI_NXT
PC8.GPIO_Label=RGB BLUE
PC8.Signal=S_TIM3_CH3
PE2.Signal=QUADSPI_BK1_IO2
PF10.Signal=QUADSPI_CLK
PF6.Signal=QUADSPI_BK1_IO3
PF8.Signal=QUADSPI_BK1_IO0
PF9.Signal=QUADSPI_BK1_IO1
PG6.Signal=QUADSPI_BK1_NCS
PH13.Signal=FDCAN1_TX
PI11.Signal=USB_OTG_HS_ULPI_DIR
PI9.Signal=FDCAN1_RX

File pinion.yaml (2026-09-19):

name: "STM32H743 CAN + USB-HS Dev Board"
description: "[Rev 1.1] STM32H743 CAN + USB-HS Dev Board - full pinout diagram"
components:
    J1:
        description: Conn_02x38_Counter_Clockwise
        pins:
            '1':
                name: GND
                description: 'Ground'
                groups: ['ground']
            '2':
                name: PA13
                description: 'STM32 IO pin'
                groups: ['io']
            '3':
                name: VBUS
                description: '5v Power input/output, will not backfeed USB ports'
                groups: ['power']
            '4':
                name: +3V3
                description: '3.3v Power, max 2A total'
                groups: ['power']
            '5':
                name: PI2
                description: 'STM32 IO pin'
                groups: ['io']
            '6':
                name: PI3
                description: 'STM32 IO pin'
                groups: ['io']
            '7':
                name: PA14
                description: 'STM32 IO pin'
                groups: ['io']
            '8':
                name: PA15
                description: 'STM32 IO pin'
                groups: ['io']
            '9':
                name: PC10
                description: 'STM32 IO pin'
                groups: ['io']
            '10':
                name: PC11
                description: 'STM32 IO pin'
                groups: ['io']
            '11':
                name: PC12
                description: 'STM32 IO pin'
                groups: ['io']
            '12':
                name: PD0
                description: 'STM32 IO pin'
                groups: ['io']
            '13':
                name: PD1
                description: 'STM32 IO pin'
                groups: ['io']
            '14':
                name: PD2
                description: 'STM32 IO pin'
                groups: ['io']
            '15':
                name: PD3
                description: 'STM32 IO pin'
                groups: ['io']
            '16':
                name: PD4
                description: 'STM32 IO pin'
                groups: ['io']
            '17':
                name: PD5
                description: 'STM32 IO pin'
                groups: ['io']
            '18':
                name: PD6
                description: 'STM32 IO pin'
                groups: ['io']
            '19':
                name: PD7
                description: 'STM32 IO pin'
                groups: ['io']
            '20':
                name: PG9
                description: 'STM32 IO pin'
                groups: ['io']
            '21':
                name: PG10
                description: 'STM32 IO pin'
                groups: ['io']
            '22':
                name: PG11
                description: 'STM32 IO pin'
                groups: ['io']
            '23':
                name: PG12
                description: 'STM32 IO pin'
                groups: ['io']
            '24':
                name: PG13
                description: 'STM32 IO pin'
                groups: ['io']
            '25':
                name: PG14
                description: 'STM32 IO pin'
                groups: ['io']
            '26':
                name: PG15
                description: 'STM32 IO pin'
                groups: ['io']
            '27':
                name: PB3
                description: 'STM32 IO pin'
                groups: ['io']
            '28':
                name: PB4
                description: 'STM32 IO pin'
                groups: ['io']
            '29':
                name: PB6
                description: 'STM32 IO pin'
                groups: ['io']
            '30':
                name: PB7
                description: 'STM32 IO pin'
                groups: ['io']
            '31':
                name: BOOT0
                description: 'Active-high Bootloader'
                groups: ['core']
            '32':
                name: PB8
                description: 'STM32 IO pin'
                groups: ['io']
            '33':
                name: PB9
                description: 'STM32 IO pin'
                groups: ['io']
            '34':
                name: PE0
                description: 'STM32 IO pin'
                groups: ['io']
            '35':
                name: PE1
                description: 'STM32 IO pin'
                groups: ['io']
            '36':
                name: PI4
                description: 'STM32 IO pin'
                groups: ['io']
            '37':
                name: PI5
                description: 'STM32 IO pin'
                groups: ['io']
            '38':
                name: PI6
                description: 'STM32 IO pin'
                groups: ['io']
            '39':
                name: PI7
                description: 'STM32 IO pin'
                groups: ['io']
            '40':
                name: PE3
                description: 'STM32 IO pin'
                groups: ['io']
            '41':
                name: PE4
                description: 'STM32 IO pin'
                groups: ['io']
            '42':
                name: PE5
                description: 'STM32 IO pin'
                groups: ['io']
            '43':
                name: PE6
                description: 'STM32 IO pin'
                groups: ['io']
            '44':
                name: PI8
                description: 'STM32 IO pin'
                groups: ['io']
            '45':
                name: PC13
                description: 'STM32 IO pin'
                groups: ['io']
            '46':
                name: PF0
                description: 'STM32 IO pin'
                groups: ['io']
            '47':
                name: PF1
                description: 'STM32 IO pin'
                groups: ['io']
            '48':
                name: PF2
                description: 'STM32 IO pin'
                groups: ['io']
            '49':
                name: PF3
                description: 'STM32 IO pin'
                groups: ['io']
            '50':
                name: PF4
                description: 'STM32 IO pin'
                groups: ['io']
            '51':
                name: PF5
                description: 'STM32 IO pin'
                groups: ['io']
            '52':
                name: PH1
                description: 'STM32 IO pin'
                groups: ['io']
            '53':
                name: PC1
                description: 'STM32 IO pin'
                groups: ['io']
            '54':
                name: PC2_C
                description: 'STM32 IO pin'
                groups: ['io']
            '55':
                name: PA0
                description: 'STM32 IO pin'
                groups: ['io']
            '56':
                name: PA1
                description: 'STM32 IO pin'
                groups: ['io']
            '57':
                name: PA2
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

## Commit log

2026-07-21 pf13, pf14, pf15, pg0, add qspi to readme
    [stm32h753_dev.kicad_pcb, stm32h753_dev.kicad_sch]
2026-07-21 change all references from 753 to 743
    [stm32h753_dev.kicad_pcb, stm32h753_dev.kicad_sch]
2026-07-21 more io routing, pinion experimentation
    [stm32h753_dev.kicad_pcb, stm32h753_dev.kicad_sch]
2026-07-23 rgb led, route io
    [stm32h753_dev.kicad_pcb, stm32h753_dev.kicad_sch]
2026-07-24 rgb gates, pinion changes
    [stm32h753_dev.kicad_pcb, stm32h753_dev.kicad_sch]
2026-07-24 power led
    [stm32h753_dev.kicad_pcb, stm32h753_dev.kicad_sch]
2026-07-24 add hugo docs
    [stm32h743_can_hs.kicad_pcb, stm32h743_can_hs.kicad_sch]
2026-07-25 via stitching, fix PF7, docs license
    [stm32h743_can_hs.kicad_pcb, stm32h743_can_hs.kicad_sch]
2026-07-25 version label on pcb
    [stm32h743_can_hs.kicad_pcb]
2026-07-26 bom changes
    [stm32h743_can_hs.kicad_pcb, stm32h743_can_hs.kicad_sch]
2026-07-27 cleanup, board rev
    [stm32h743_can_hs.kicad_pcb, stm32h743_can_hs.kicad_sch]
2026-07-27 fix field warnings, erc, drc, vias
    [stm32h743_can_hs.kicad_pcb, stm32h743_can_hs.kicad_sch]
2026-07-30 board cleanup, change can xciever to TI
    [stm32h743_can_hs.kicad_pcb, stm32h743_can_hs.kicad_sch]
2026-07-30 update pinion outputs, pcb cleanup
    [stm32h743_can_hs.kicad_pcb]
2026-08-06 cad models
2026-08-06 website updates, oshwa mark
    [stm32h743_can_hs.kicad_pcb]
2026-08-11 changes for production, fix cad models
    [stm32h743_can_hs.kicad_pcb, stm32h743_can_hs_full.step, stm32h743_can_hs_simplified.step]
2026-09-06 fix buck ic part numbers
    [stm32h743_can_hs.kicad_pcb, stm32h743_can_hs.kicad_sch]
2026-09-09 minor pcb cleanup, fixed bom
    [stm32h743_can_hs.kicad_pcb, stm32h743_can_hs.kicad_sch]
2026-09-09 updated website imagery, pcbway promo
2026-09-09 Revise README with new image and sponsorship details
    Updated board image and project title. Added sponsorship information from PCBWay.
2026-09-13 sch: fix led symbol
    [stm32h743_can_hs.kicad_pcb, stm32h743_can_hs.kicad_sch]
2026-09-19 replace debug header with stdc14, add PA13 to I/O, split pinion/ibom between versions
    [FTSH-107-01-L-DV-K.stp, stm32h743_can_hs.kicad_pcb, stm32h743_can_hs.kicad_sch]
2026-09-19 sch, pcb: FTSH-107-01-L-DV-K-A PN
    [stm32h743_can_hs.kicad_pcb, stm32h743_can_hs.kicad_sch]
2026-09-19 remove OSHWA silkscreen for now
    [stm32h743_can_hs.kicad_pcb]
2026-09-26 led fixes
    [stm32h743_can_hs.kicad_pcb, stm32h743_can_hs.kicad_sch]

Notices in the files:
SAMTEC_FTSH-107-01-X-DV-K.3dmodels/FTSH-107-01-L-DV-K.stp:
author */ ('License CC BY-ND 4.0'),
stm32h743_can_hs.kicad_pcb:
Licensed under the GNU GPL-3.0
